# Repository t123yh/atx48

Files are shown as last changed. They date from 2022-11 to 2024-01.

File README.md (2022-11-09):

# ATX48: 48V DC-ATX Power Supply

An isolated 44V-70V to ATX power supply. Built for DC UPS systems for your home datacenter.

## Structure

Structure

## Features

### Hot Plug with Soft Start

LM5067 hot swap controller is used to limit inrush current, eliminating any sparks on hot-plug. It also limits input current to 10A, protecting over-current situations.

### High efficiency conversion

[Huawei GDQ33S12B/P](https://www.huaweipowersolutions.com/GDQ33S12B(P).pdf) is used as the main converter. It provides 12V/33A output with up to 96.0% efficiency.

For 3.3V and 5V, three ZXDN10 modules are used (3.3V motherboard, 5V motherboard, 5V HDD), with up to 94% efficiency (See [testing](https://blog.iccfish.com/2021/08/02/%E7%9B%98%E4%B8%80%E4%B8%8B%E6%9C%80%E8%BF%91%E6%94%B6%E5%88%B0%E7%9A%84%E4%BA%8C%E6%89%8Bdc%E9%9D%9E%E9%9A%94%E7%A6%BB%E9%99%8D%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)).

5VSB voltage is provided by an AV10-48S05 module, with up to 10W standby power output. The main converter is disabled in standby mode to avoid unnecessary energy waste when PC is off.

This power supply does not provide -12V and -5V output, because no motherboards use them today.

### Fully isolated
Input and output are fully isolated. Works within either +48V or -48V setup.

### LED indicators

Built with 8 LED indicators to monitor input and output status (see photos below).

### ATX installation

Installs to any chassis with ATX power slot.

## Connectors

### Input

An XT60PB-M connector is present on board. Use any XT60 compatible connector as power input.

### Output

This power supply provides the following power outputs:

* 1 \* ATX 24-Pin
* 2 \* 8-Pin 12V for CPU and PCIe
* 2 \* 4-Pin for SATA

For 24-Pin ATX power output, use a 24P to 24P cable with identical pinouts.

For SATA HDD/SDD power output, use Lenovo 4-Pin to SATA connector, such as [this](https://www.amazon.com/Genuine-Lenovo-7-5mm-Power-54Y8286/dp/B07DL9P1V7).

For PCIe / CPU 8-Pin power, use 12V modular cables for Seasonic FOCUS+/KM3/XP2/XM2/XP3 series.
 
## Photos

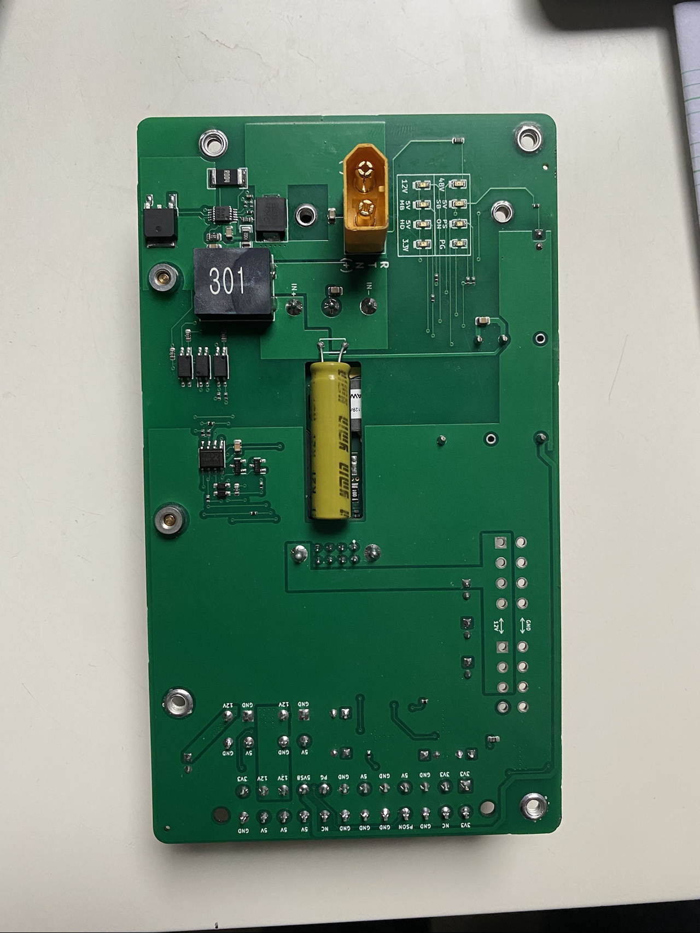
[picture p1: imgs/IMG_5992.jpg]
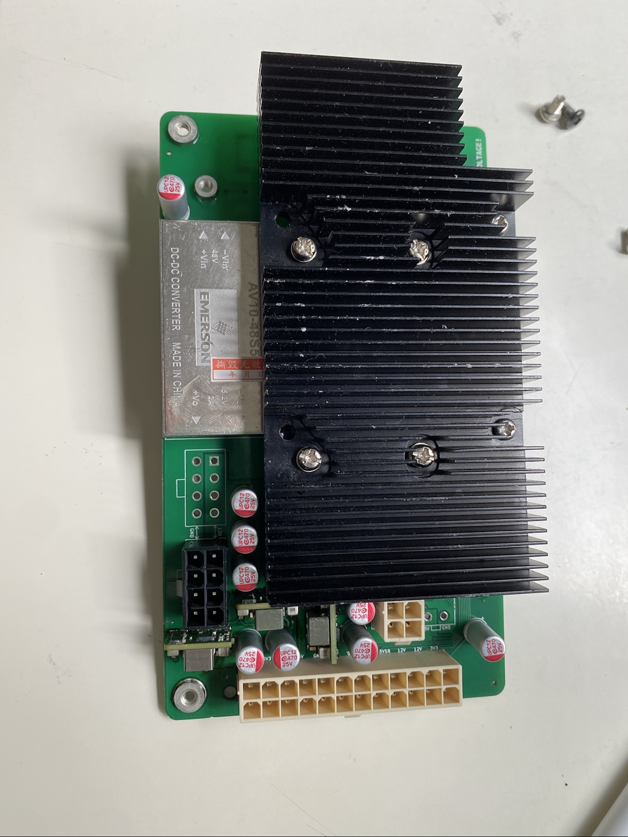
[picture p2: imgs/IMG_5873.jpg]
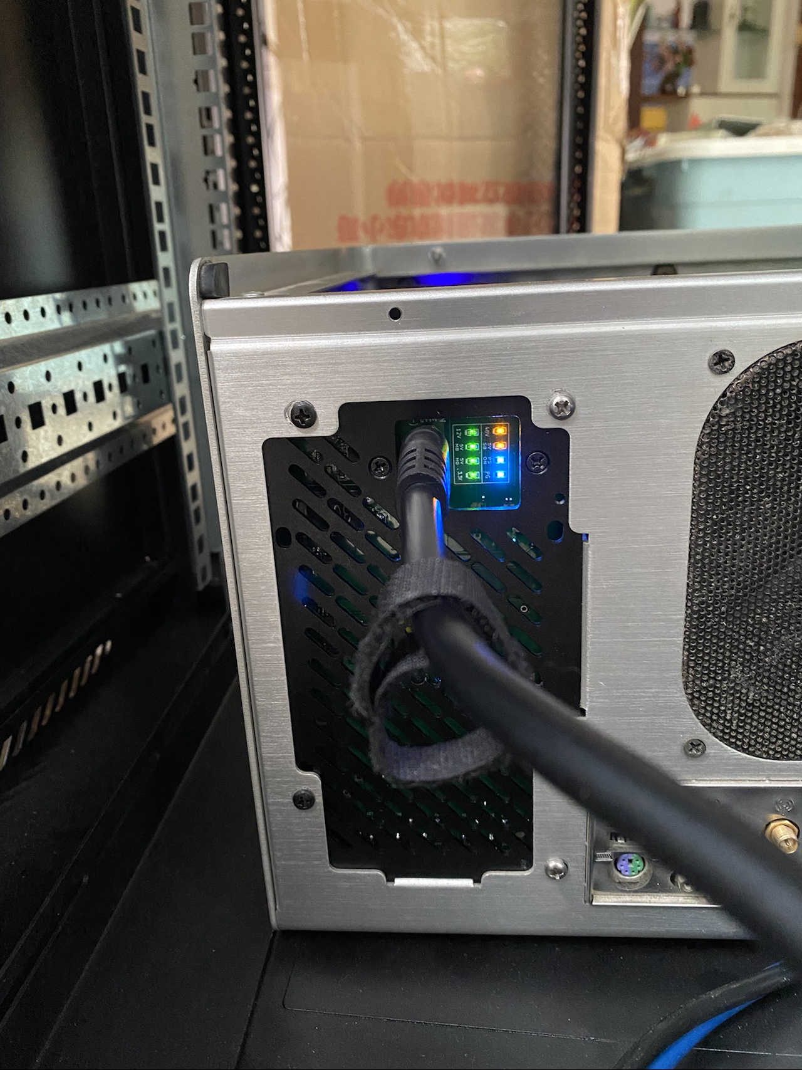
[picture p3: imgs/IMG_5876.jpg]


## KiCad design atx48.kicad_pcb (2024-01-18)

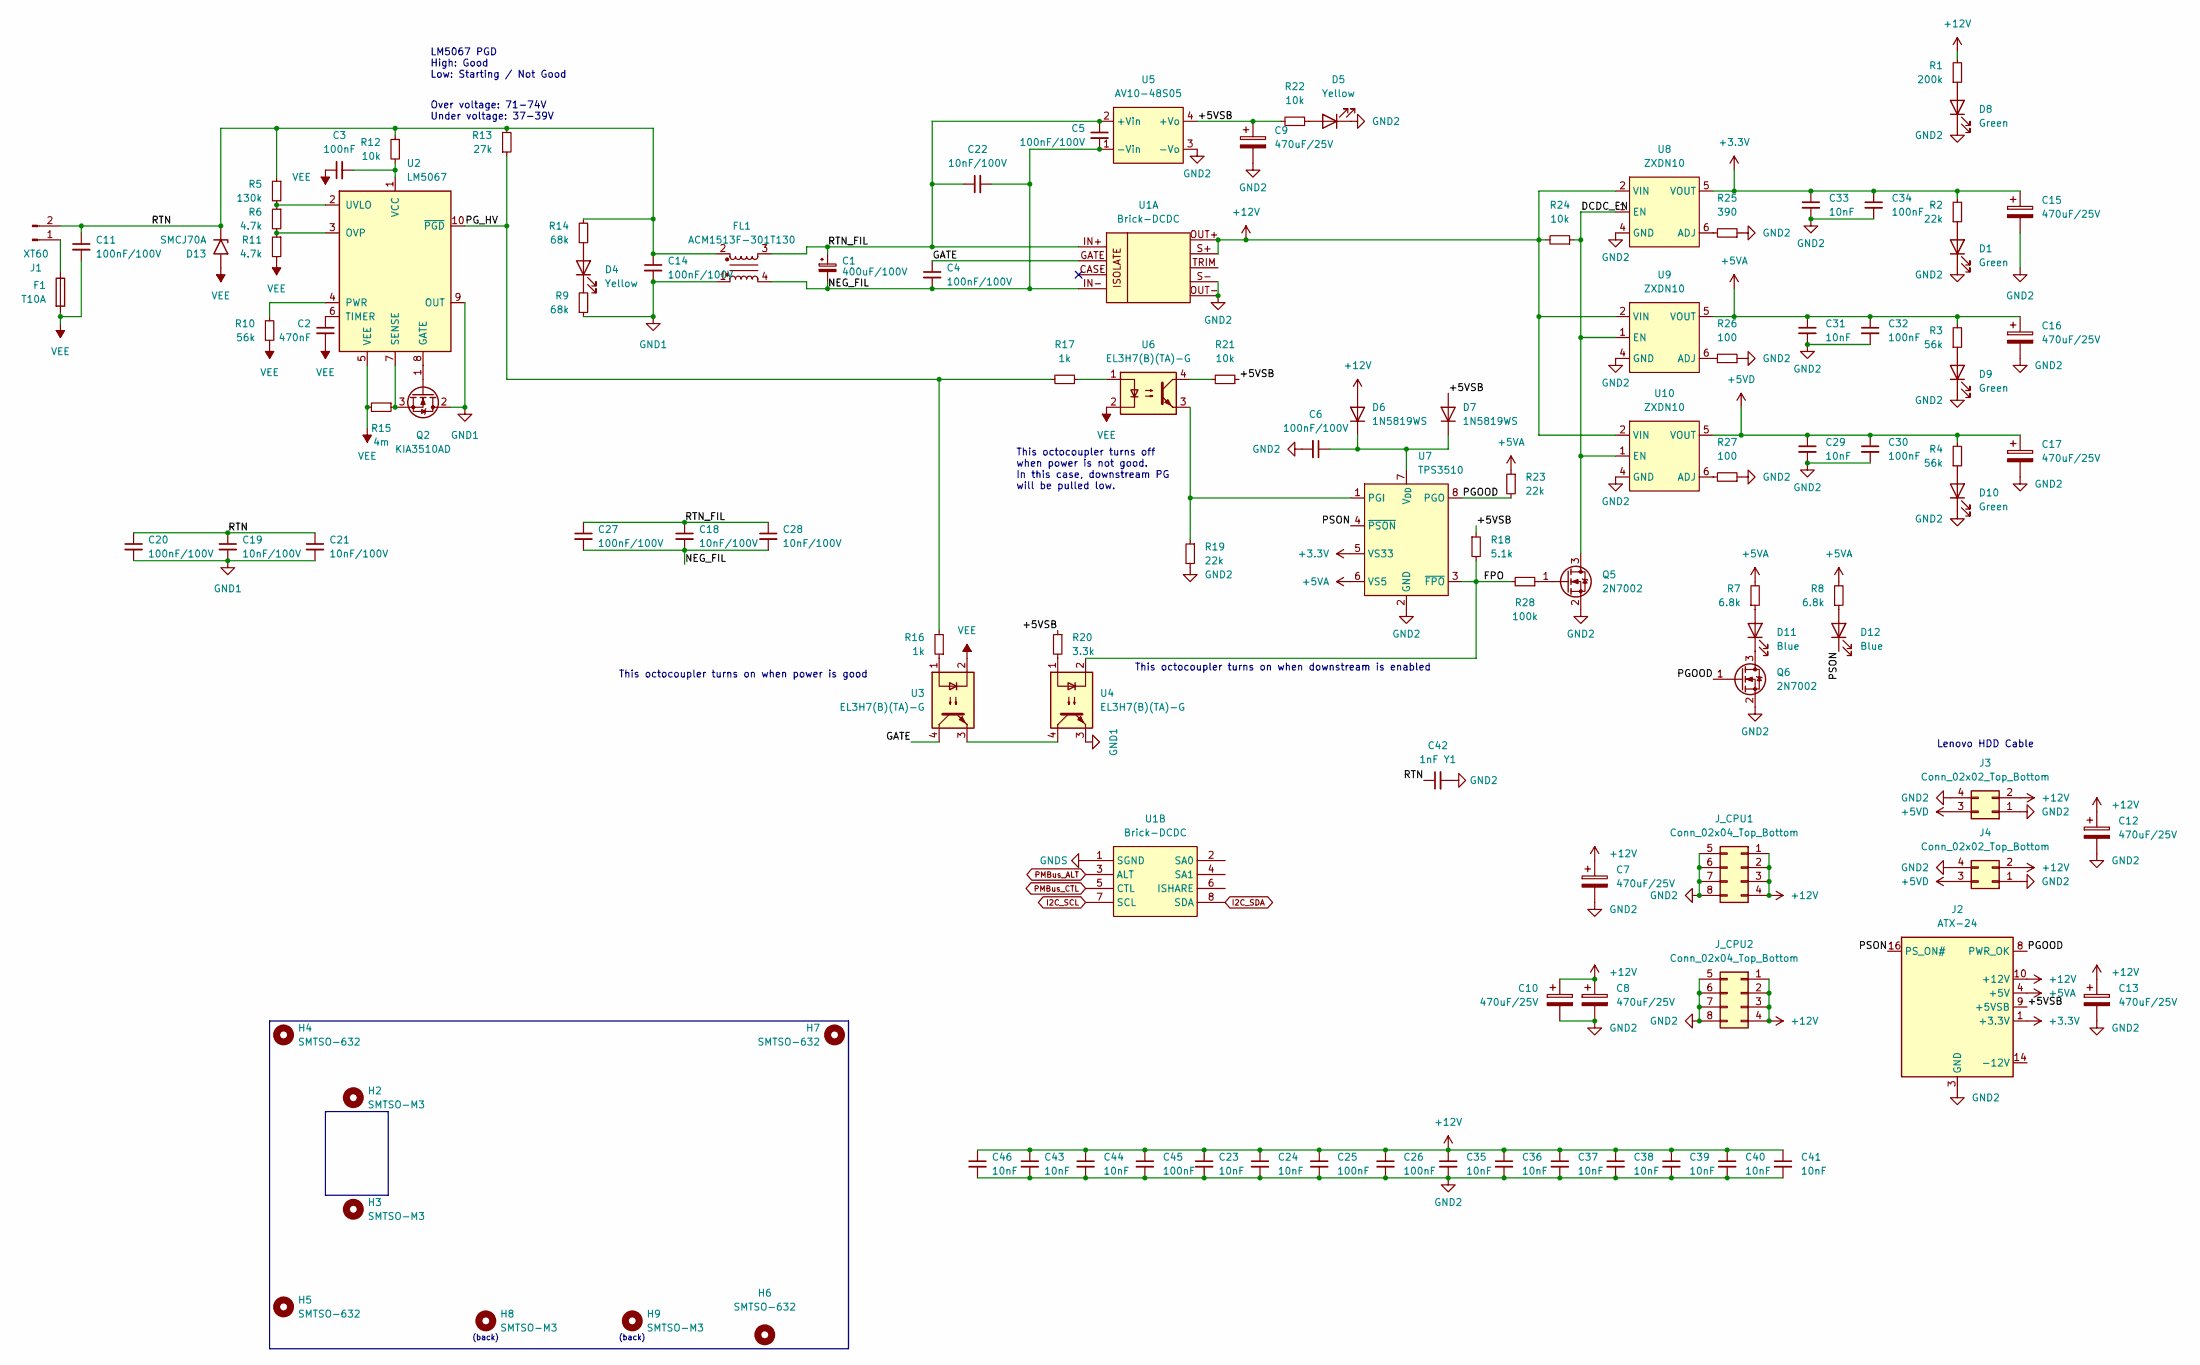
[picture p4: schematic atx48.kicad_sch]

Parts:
C1: 400uF/100V; C_Disc_D5.0mm_W2.5mm_P5.00mm
C2: 470nF; 0402_C
C3, C25, C26, C30, C32, C34, C45: 100nF; 0805_C
C4, C5, C6, C11, C14, C20, C27: 100nF/100V; 0805_C
C7, C8, C9, C10, C12, C13, C15, C16, C17: 470uF/25V; CP_Radial_D6.3mm_P2.50mm
C18, C19, C21, C22, C28: 10nF/100V; 0603_C
C23, C24, C29, C31, C33, C35, C36, C37, C38, C39, C40, C41, C43, C44, C46: 10nF; 0603_C
C42: 1nF Y1; C_Disc_D8.0mm_W5.0mm_P10.00mm
D1, D8, D9, D10: Green; 0603_LED_S1_NUM
D4, D5: Yellow; 0603_LED_S1_NUM
D6, D7: 1N5819WS; SOD-323
D11, D12: Blue; 0603_LED_S1_NUM
D13: SMCJ70A; D_SMC
F1: T10A; Fuse_1812_4532Metric
FL1: ACM1513F-301T130; ACM1513
H2, H3, H8, H9: SMTSO-M3; MountingHole_SMTSO-M3
H4, H5, H6, H7: SMTSO-632; MountingHole_SMTSO-632
J1: XT60; AMASS_XT60-M_1x02_P7.20mm_Vertical
J2: ATX-24; ATX-24P
J3, J4: Conn_02x02_Top_Bottom; ATX-4P
J_CPU1, J_CPU2: Conn_02x04_Top_Bottom; ATX-8P-Square
Q2: KIA3510AD; TO-252-2
Q5, Q6: 2N7002; SOT-23
R1: 200k; 0402_R
R2, R19, R23: 22k; 0402_R
R3, R4, R10: 56k; 0402_R
R5: 130k; 0603_R
R6, R11: 4.7k; 0402_R
R7, R8: 6.8k; 0402_R
R9, R14: 68k; 0603_R
R12: 10k; 1206_R
R13: 27k; 0805_R
R15: 4m; 2512_R
R16, R17: 1k; 0603_R
R18: 5.1k; 0402_R
R20: 3.3k; 0402_R
R21, R22: 10k; 0402_R
R24: 10k; 0603_R
R25: 390; 0603_R
R26, R27: 100; 0402_R
R28: 100k; 0402_R
U1: Brick-DCDC; Quarter-Brick-PMBus
U2: LM5067; MSOP-10_3x3mm_P0.5mm
U3, U4, U6: EL3H7(B)(TA)-G; SOP-4_4.4x2.6mm_P1.27mm
U5: AV10-48S05; AV10-48Sxx
U7: TPS3510; SOIC-8_3.9x4.9mm_P1.27mm
U8, U9, U10: ZXDN10

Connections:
+3.3V: C15.1, C33.1, C34.1, J2.1 (+3.3V), J2.2 (+3.3V), J2.12 (+3.3V), J2.13 (+3.3V), R2.2, U7.5 (VS33), U8.5 (VOUT)
+5VA: C16.1, C31.1, C32.1, J2.4 (+5V), J2.6 (+5V), J2.21 (+5V), J2.22 (+5V), J2.23 (+5V), R3.2, R7.2, R8.2, R23.1, U7.6 (VS5), U9.5 (VOUT)
+5VD: C17.1, C29.1, C30.1, J3.3, J4.3, R4.2, U10.5 (VOUT)
+12V: C7.1, C8.1, C10.1, C12.1, C13.1, C23.1, C24.1, C25.1, C26.1, C35.1, C36.1, C37.1, C38.1, C39.1, C40.1, C41.1, C43.1, C44.1, C45.1, C46.1, D6.2 (A), J2.10 (+12V), J2.11 (+12V), J3.2, J4.2, J_CPU1.1, J_CPU1.2, J_CPU1.3, J_CPU1.4, J_CPU2.1, J_CPU2.2, J_CPU2.3, J_CPU2.4, R1.2, R24.2, U1.OUT+, U1.S+, U8.2 (VIN), U9.2 (VIN), U10.2 (VIN)
/+5VSB: C9.1, D7.2 (A), J2.9 (+5VSB), R18.1, R20.1, R21.1, R22.2, U5.4 (+Vo)
/DCDC_EN: Q5.3 (D), R24.1, U8.1 (EN), U9.1 (EN), U10.1 (EN)
/FPO: R18.2, R28.2, U4.2, U7.3 (~FPO)
/GATE: C4.1, U1.GATE, U3.4
/NEG_FIL: C1.2, C4.2, C5.2, C18.2, C22.2, C27.2, C28.2, FL1.4, U1.IN-, U5.1 (-Vin)
/PGOOD: J2.8 (PWR_OK), Q6.1 (G), R23.2, U7.8 (PGO)
/PG_HV: R13.1, R16.2, R17.2, U2.10 (~PGD)
/PSON: D12.1 (K), J2.16 (PS_ON#), U7.4 (~PSON)
/RTN: C11.1, C14.1, C19.1, C20.1, C21.1, C42.1, D13.1 (A1), FL1.2, J1.2, R5.1, R12.1, R13.2, R14.2
/RTN_FIL: C1.1, C5.1, C18.1, C22.1, C27.1, C28.1, FL1.3, U1.IN+, U5.2 (+Vin)
GND1: C14.2, C19.2, C20.2, C21.2, FL1.1, Q2.2 (D), R9.1, U2.9 (OUT), U4.3
GND2: C6.2, C7.2, C8.2, C9.2, C10.2, C12.2, C13.2, C15.2, C16.2, C17.2, C23.2, C24.2, C25.2, C26.2, C29.2, C30.2, C31.2, C32.2, C33.2, C34.2, C35.2, C36.2, C37.2, C38.2, C39.2, C40.2, C41.2, C42.2, C43.2, C44.2, C45.2, C46.2, D1.1 (K), D5.1 (K), D8.1 (K), D9.1 (K), D10.1 (K), J2.3 (GND), J2.5 (GND), J2.7 (GND), J2.15 (GND), J2.17 (GND), J2.18 (GND), J2.19 (GND), J2.24 (GND), J3.1, J3.4, J4.1, J4.4, J_CPU1.5, J_CPU1.6, J_CPU1.7, J_CPU1.8, J_CPU2.5, J_CPU2.6, J_CPU2.7, J_CPU2.8, Q5.2 (S), Q6.2 (S), R19.2, R25.1, R26.1, R27.1, U1.OUT-, U1.S-, U5.3 (-Vo), U7.2 (GND), U8.3 (GND), U8.4 (GND), U9.3 (GND), U9.4 (GND), U10.3 (GND), U10.4 (GND)
GNDS: U1.1 (SGND)
I2C_SCL: U1.7 (SCL)
I2C_SDA: U1.8 (SDA)
unnamed: D1.2 (A), R2.1
unnamed: D4.2 (A), R14.1
unnamed: D4.1 (K), R9.2
unnamed: D5.2 (A), R22.1
unnamed: C6.1, D6.1 (K), D7.1 (K), U7.7 (V_{DD})
unnamed: D8.2 (A), R1.1
unnamed: D9.2 (A), R3.1
unnamed: D10.2 (A), R4.1
unnamed: D11.2 (A), R7.1
unnamed: D11.1 (K), Q6.3 (D)
unnamed: D12.2 (A), R8.1
unnamed: F1.1, J1.1
unnamed: Q2.1 (G), U2.8 (GATE)
unnamed: Q2.3 (S), R15.1, U2.7 (SENSE)
unnamed: Q5.1 (G), R28.1
unnamed: R16.1, U3.1
unnamed: R17.1, U6.1
unnamed: R20.2, U4.1
unnamed: R21.2, U6.4
unnamed: R6.2, R11.1, U2.3 (OVP)
unnamed: R10.2, U2.4 (PWR)
unnamed: C2.1, U2.6 (TIMER)
unnamed: R5.2, R6.1, U2.2 (UVLO)
unnamed: C3.2, R12.2, U2.1 (VCC)
unnamed: U3.3, U4.4
unnamed: R19.1, U6.3, U7.1 (PGI)
unnamed: R25.2, U8.6 (ADJ)
unnamed: R26.2, U9.6 (ADJ)
unnamed: R27.2, U10.6 (ADJ)
PMBus_ALT: U1.3 (ALT)
PMBus_CTL: U1.5 (CTL)
VEE: C2.2, C3.1, C11.2, D13.2 (A2), F1.2, R10.1, R11.2, R15.2, U2.5 (VEE), U3.2, U6.2

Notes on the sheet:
Over voltage: 71-74V Under voltage: 37-39V
This octocoupler turns off when power is not good. In this case, downstream PG will be pulled low.
This octocoupler turns on when downstream is enabled
Lenovo HDD Cable
(back)
LM5067 PGD High: Good Low: Starting / Not Good
This octocoupler turns on when power is good

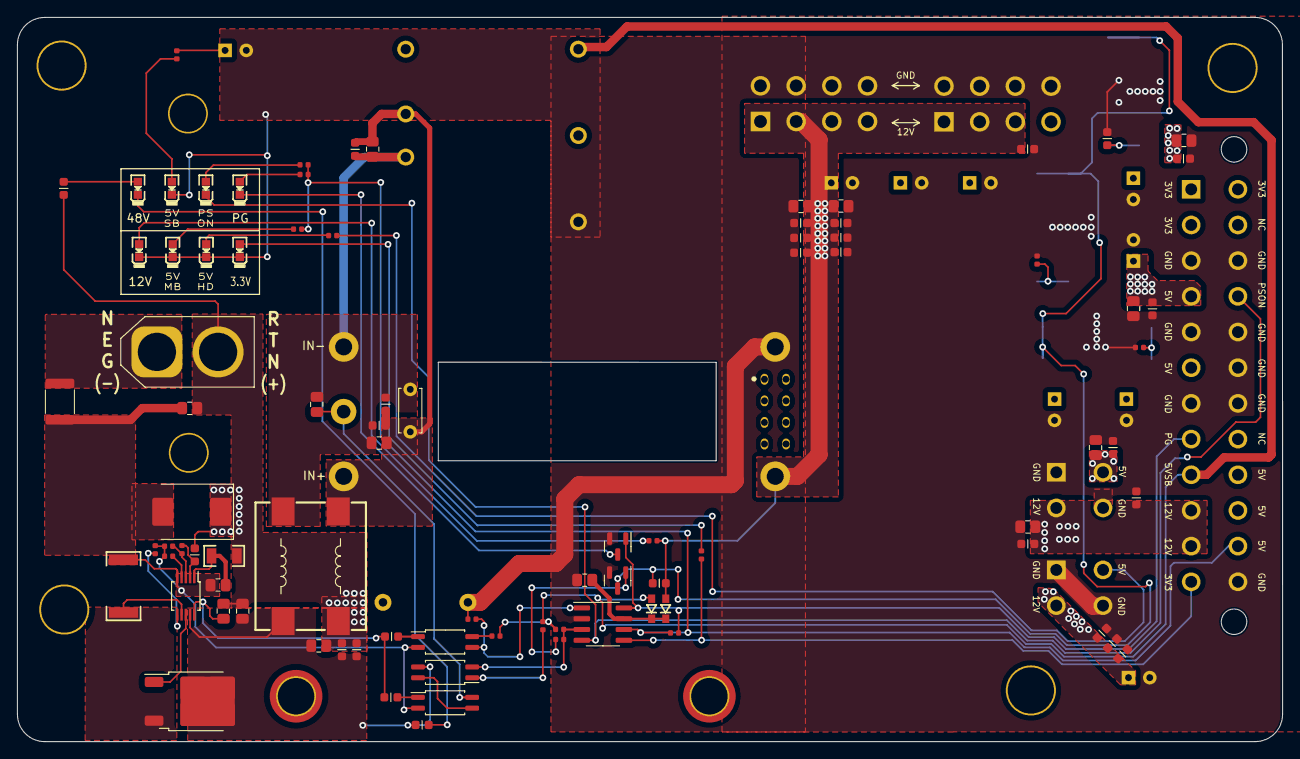
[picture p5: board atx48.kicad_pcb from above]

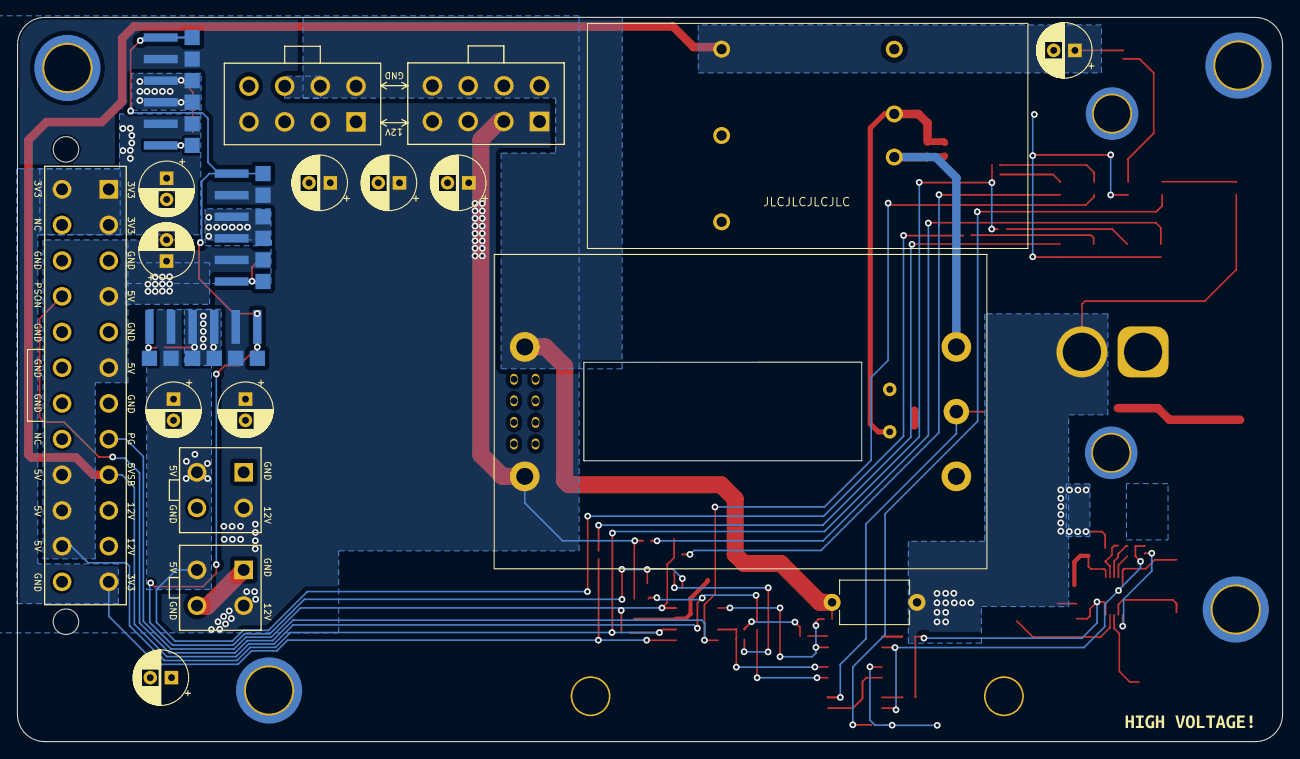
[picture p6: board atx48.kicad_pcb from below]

Board: 2 copper layers, 148.9 x 85.2 mm, 115 parts (26 on the bottom side), 46 nets.

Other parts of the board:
kibuzzard-62760563: G***; kibuzzard-62760563

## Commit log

2022-05-07 pmbus and normal
    [hw-satcom-psu-adapter.kicad_pcb, hw-satcom-psu-adapter.kicad_sch]
2022-05-07 change fuse footprint
    [hw-satcom-psu-adapter.kicad_pcb, hw-satcom-psu-adapter.kicad_sch]
2022-10-17 change mounting hole
    [hw-satcom-psu-adapter.kicad_pcb]
2022-10-18 Layout improvements
    [hw-satcom-psu-adapter.kicad_pcb, hw-satcom-psu-adapter.kicad_sch]
2022-10-26 Adjust low voltage copper pour
    [hw-satcom-psu-adapter.kicad_pcb]
2022-10-26 Adjust screw hole position
    [hw-satcom-psu-adapter.kicad_pcb]
2022-10-26 Reduce LED brightness
    [hw-satcom-psu-adapter.kicad_pcb, hw-satcom-psu-adapter.kicad_sch]
2022-11-05 Revert "Adjust screw hole position"
    This reverts commit 63cac71901258e286d442f6c161a0cf4eb18ce6f.
    [hw-satcom-psu-adapter.kicad_pcb]
2022-11-09 Enhance grouding
    [atx48.kicad_pcb]
2024-01-18 Add filter capacitors; add Y cap
    [atx48.kicad_pcb, atx48.kicad_sch]
